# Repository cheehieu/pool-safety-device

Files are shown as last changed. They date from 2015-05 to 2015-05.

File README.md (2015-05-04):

pool-safety-device
==================

<iframe width="640" height="480" src="https://sketchfab.com/models/5c79c15477054004a583eb45c18d26ab/embed" frameborder="0" allowfullscreen mozallowfullscreen="true" webkitallowfullscreen="true" onmousewheel=""></iframe>

<p style="font-size: 13px; font-weight: normal; margin: 5px; color: #4A4A4A;">
    <a href="https://sketchfab.com/models/5c79c15477054004a583eb45c18d26ab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" target="_blank" style="font-weight: bold; color: #1CAAD9;">Pool Safety Device</a>
    by <a href="https://sketchfab.com/hieu?utm_source=oembed&utm_medium=embed&utm_campaign=5c79c15477054004a583eb45c18d26ab" target="_blank" style="font-weight: bold; color: #1CAAD9;">hieu</a>
    on <a href="https://sketchfab.com?utm_source=oembed&utm_medium=embed&utm_campaign=5c79c15477054004a583eb45c18d26ab" target="_blank" style="font-weight: bold; color: #1CAAD9;">Sketchfab</a>
</p>

## Overview

Collaborating with marketing and fine arts students, we designed a device to prevent children from drowning in home swimming pools. The device consisted of two parts: an external sensor (wristband worn by the user), and an internal control panel (base station mounted in the home).

This project was developed in the spring of 2011 for USC's Embedded System Design Laboratory (EE-459) course, taught by professor Allan Weber. It was a senior capstone design, which involved the specification, design, implementation, testing, and documentation of a digital system project using embedded processors, programmable logic, analog I/O interfaces and application specific hardware. My engineering teammates included Christopher Cortes, Bauryrzhan Krykpayev, Alexander Nobles, Steven Spinn, and Steph Shinohara.

## Hardware
The wristband alert system contains a water-detection circuit, which uses the conductivity of water to bridge the connection between two probes. Once water is detected&mdash;indicating unwanted pool access&mdash;a message is sent to the base station over an RF link, which then sounds an alarm to alert the homeowners. 

### Electrical Prototype
A functional prototype was built on wire-wrapped boards. The wristband prototype housed the op amp based water detection circuit, Freescale MC908JL15 microcontroller, wireless RF transceiver, monochromatic graphic LCD, 4MHz clock, voltage regulator, battery monitor, buzzer, and push-buttons/LEDs for user input/output. 



The base station prototype included a 24x2 character display, 4x4 keypad interface and encoder, Freescale MC908JL15 microcontroller, wireless RF transceiver, and a high-decibel buzzer.



A mockup PCB was designed to ensure the prototype could fit on a watchface-sized wristband. Not including the batteries, all of the electrical components can fit on the back of the LCD, which is 45mm x 45mm.  The thickness is about 4mm.



### Production Mockup
A production-ready mockup was created in collaboration with marketing and fine arts students. With their expertise, we developed a product that was both commercially viable and aesthetically pleasing.





## Software

### Wristband
The wristband is used to display and communicate status to a base station monitor. Once the presence of water is detected, the LEDs and buzzer alert the user of unwanted pool access. A GPIO interrupt is then generated on the microcontroller, commanding it to transmit the alert status to the monitor. 

The RFM22B 433MHz ISM band wireless transceiver uses a standard 4-wire SPI interface to communicate with the microcontroller. Because the JL16 does not have dedicated SPI pins, the serial protocol was implemented in software on GPIO lines (bit banging). This entailed writing low-level software functions to perform reading and writing of the transceiver’s registers, which involved controlling the clock, data, and device select pins.

The LCD features a battery life indicator, which displays the output of an 8-bit ADC used to monitor the system voltage input. The display also features a fish animation to entertain the child user. 

<iframe width="560" height="315" src="https://www.youtube.com/embed/oqmXTrBO6uU" frameborder="0" allowfullscreen></iframe>

### Base Station
The RF transceiver is used to provide a wireless communication interface for both the wristband and the base station monitor, allowing transmission of the alarm signal as well as a few other remote functions.

The "Sync" function establishes a connection between the wristband and base station. If the two devices are not synchronized, then any action that the wristband does will not be acted upon by the base station, and vice-versa. The Sync function is achieved through a series of handshaking between the wristband and the base station monitor. Both devices will display a message if the sync is successful.

The "Locate" function is designed to allow the user to find a misplaced wristband by emitting a continuous beep from the wristband. When the user selects the Locate function in the monitor's menu, all wristbands synced with the base station will begin to beep.

When the alarm is enabled, the wristband will send out an alarm packet on the transceiver if it detects water on its water detection circuit. When the base station receives the alarm, it checks its wristband list for a match on the ID bytes. If they match, a warning message is displayed the the buzzer alarm sounds. The user must then enter their password to disable the system, which will stop the alarm.



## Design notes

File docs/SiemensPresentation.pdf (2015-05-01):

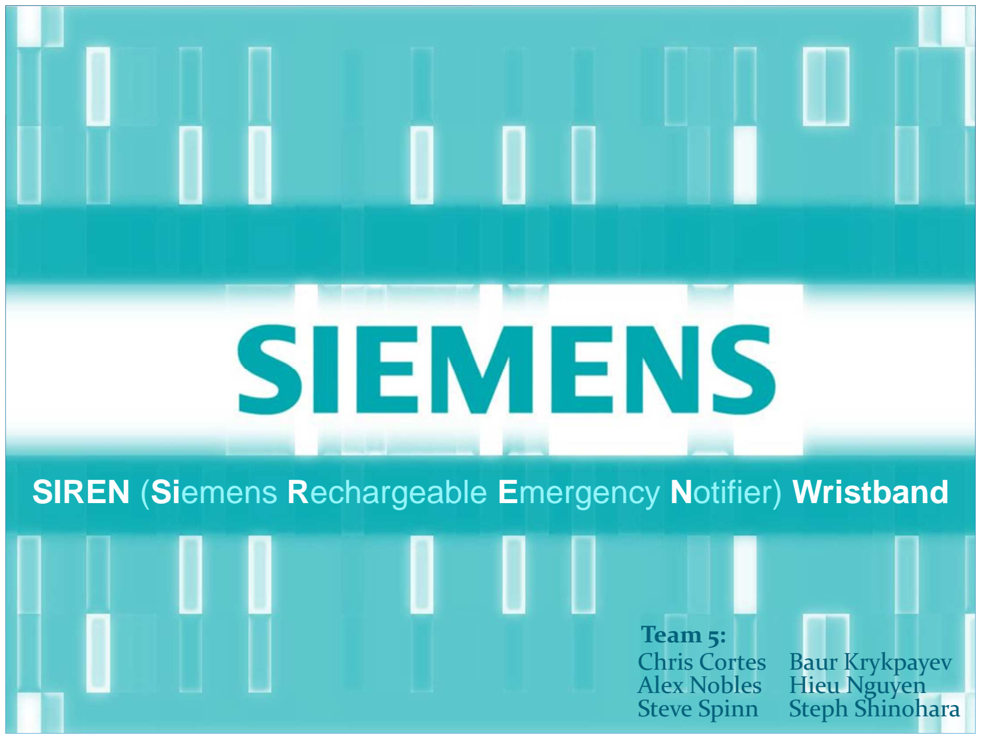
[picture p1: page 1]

Team 5:

SIREN (Siemens Rechargeable Emergency Notifier) Wristband

Chris Cortes
Alex Nobles
Steve Spinn

Baur Krykpayev
Hieu Nguyen Steph Shinohara

# Agenda

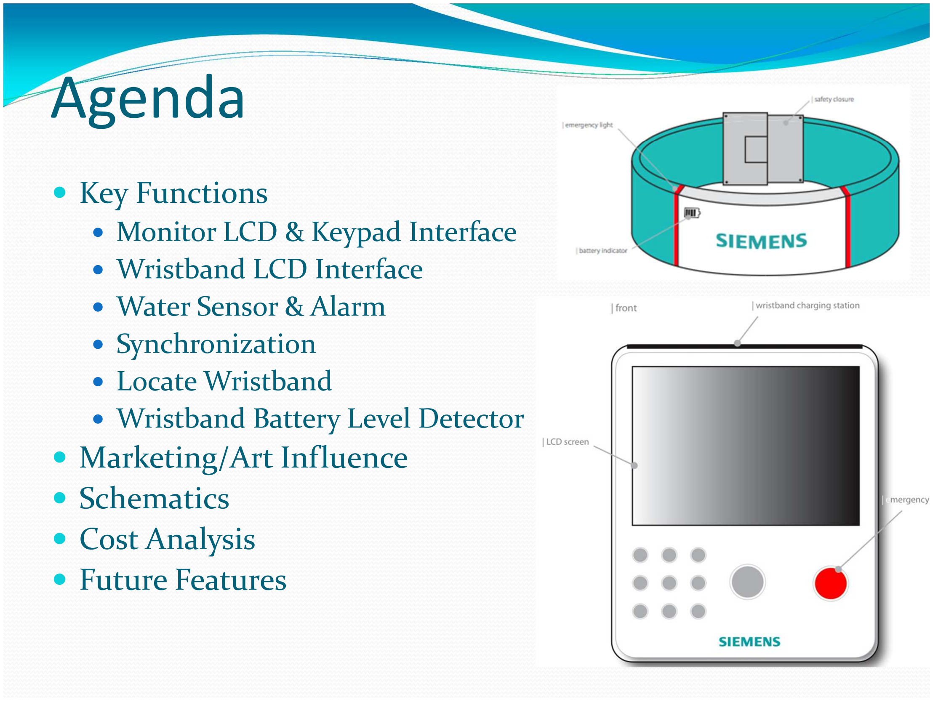
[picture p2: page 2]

Key Functions
Monitor LCD & Keypad Interface Wristband LCD Interface
Water Sensor & Alarm
Synchronization
Locate Wristband
Wristband Battery Level Detector Marketing/Art Influence
Schematics
Cost Analysis
Future Features

# Marketing/Art Influence

Based parts choices on Marketing plan
Chose cheaper, more reliable design

Art students had idea to include graphic LCD to entertain child

Added more functionality to this idea and displayed status on screen

## Monitor LCD & Keypad Interface

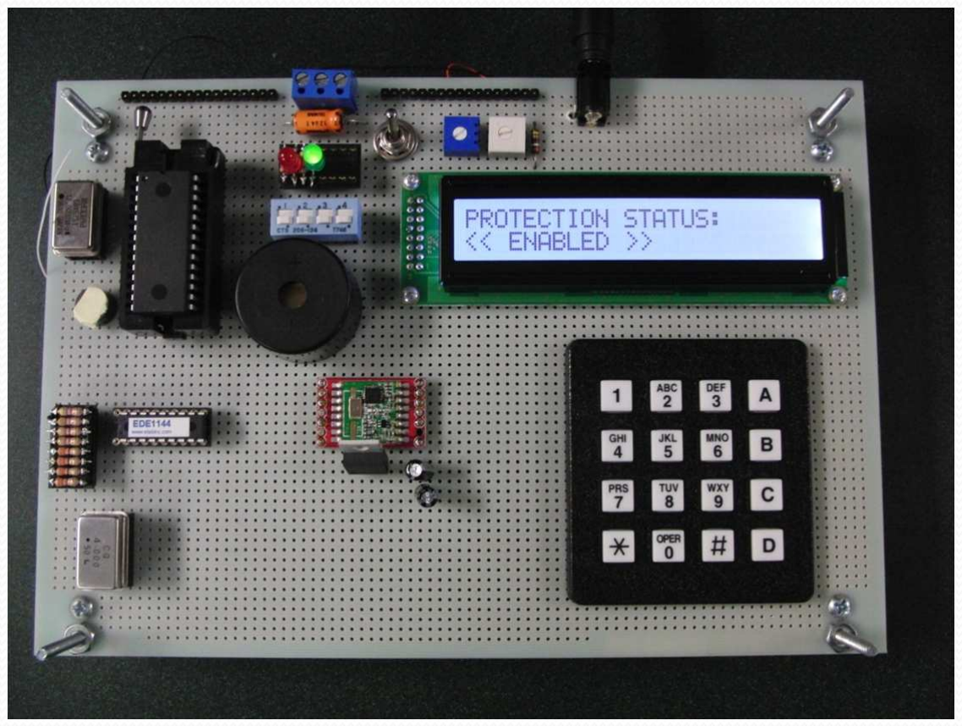
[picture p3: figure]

LCD: 24 x 2 character screen

User input: 4 x 4 keypad

Security: 4-digit password

Power Source: 5V Wall Adapter Configurable for
rechargeable battery

Audio: alert buzzer, keypad feedback

# Monitor Schematic

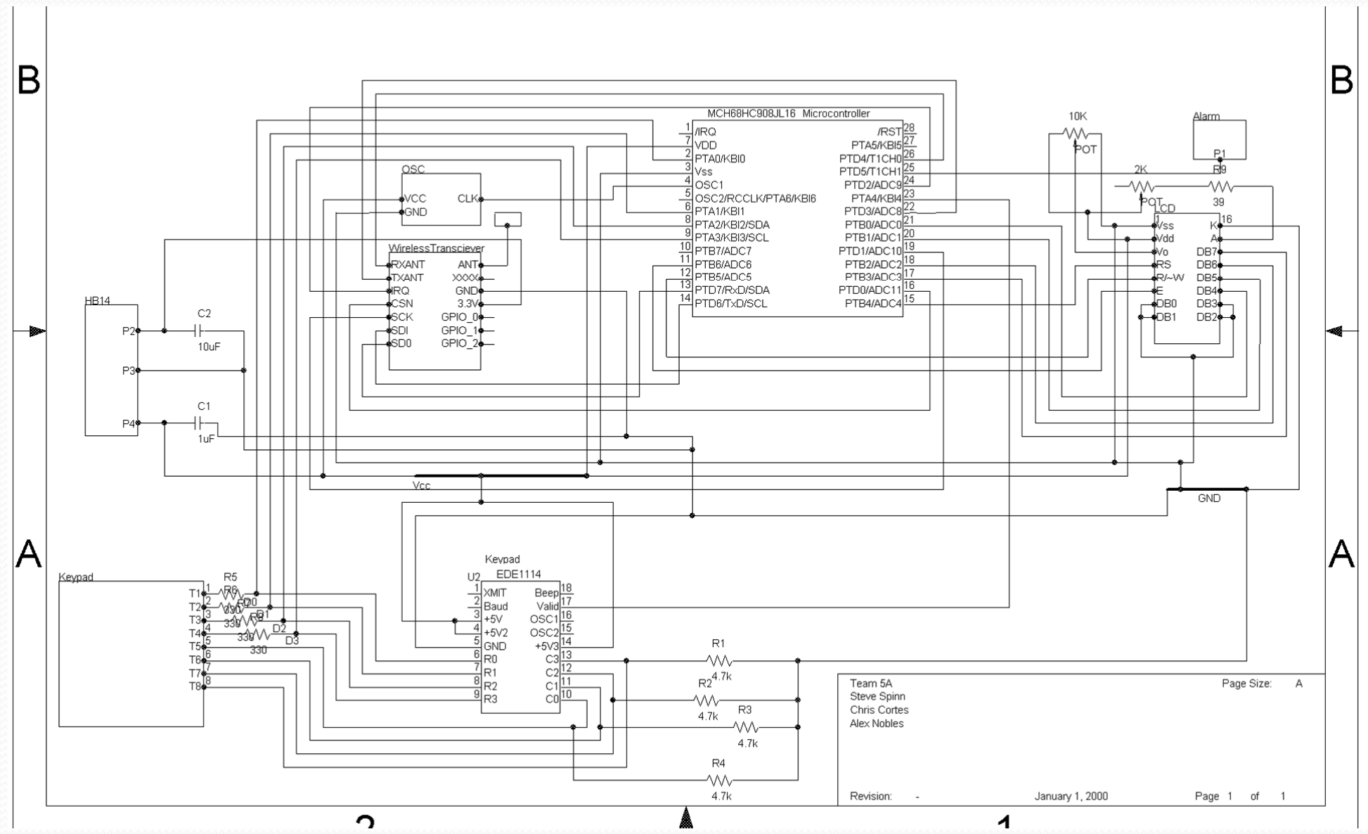
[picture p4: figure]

# Wristband Components

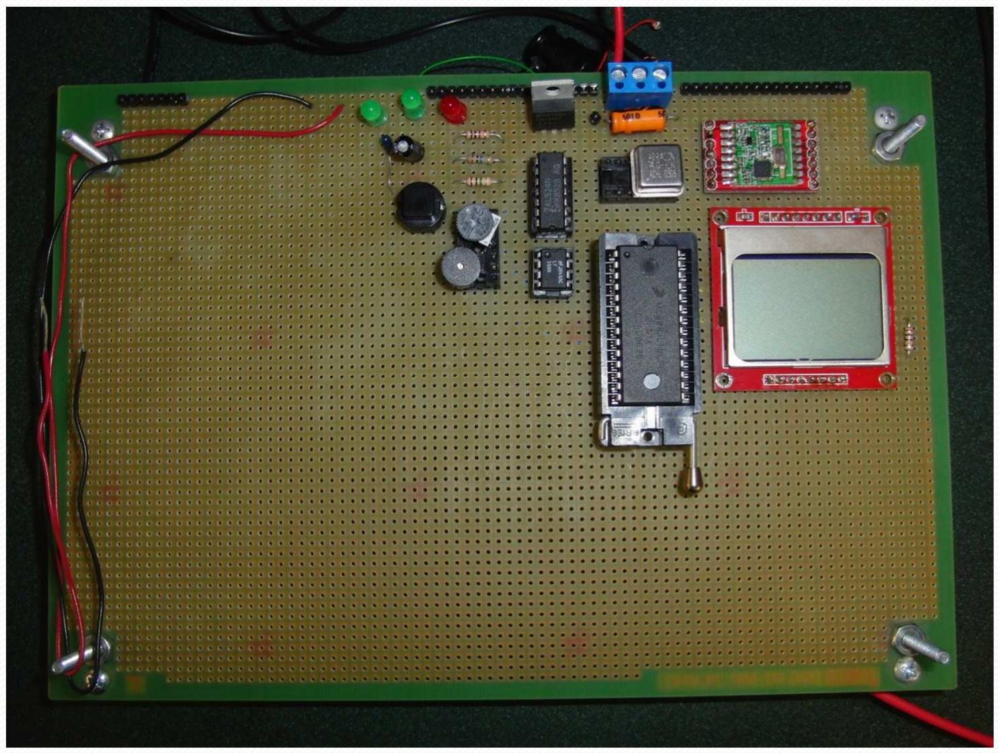
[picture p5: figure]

# Printed Circuit Board

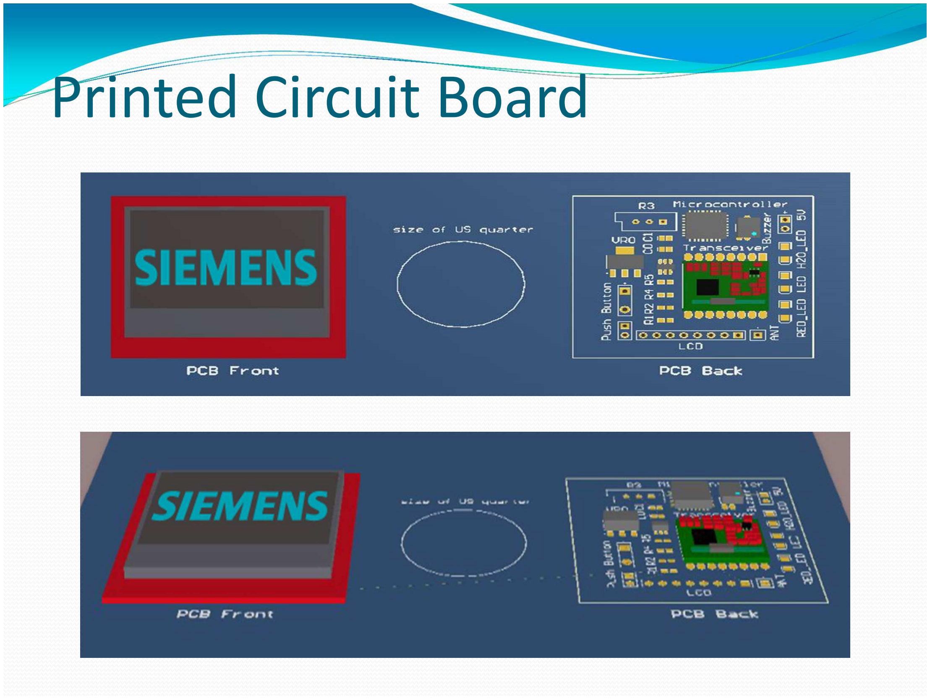
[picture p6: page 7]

# Wristband Schematic

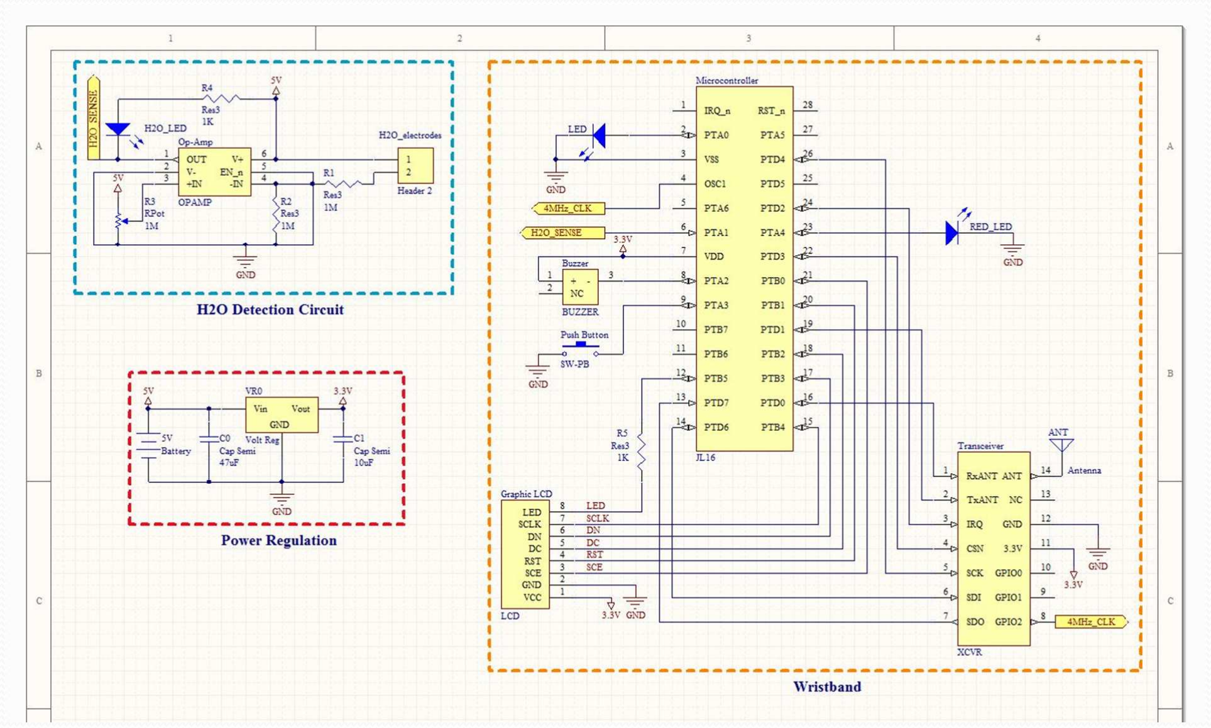
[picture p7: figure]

# Wristband LCD Interface

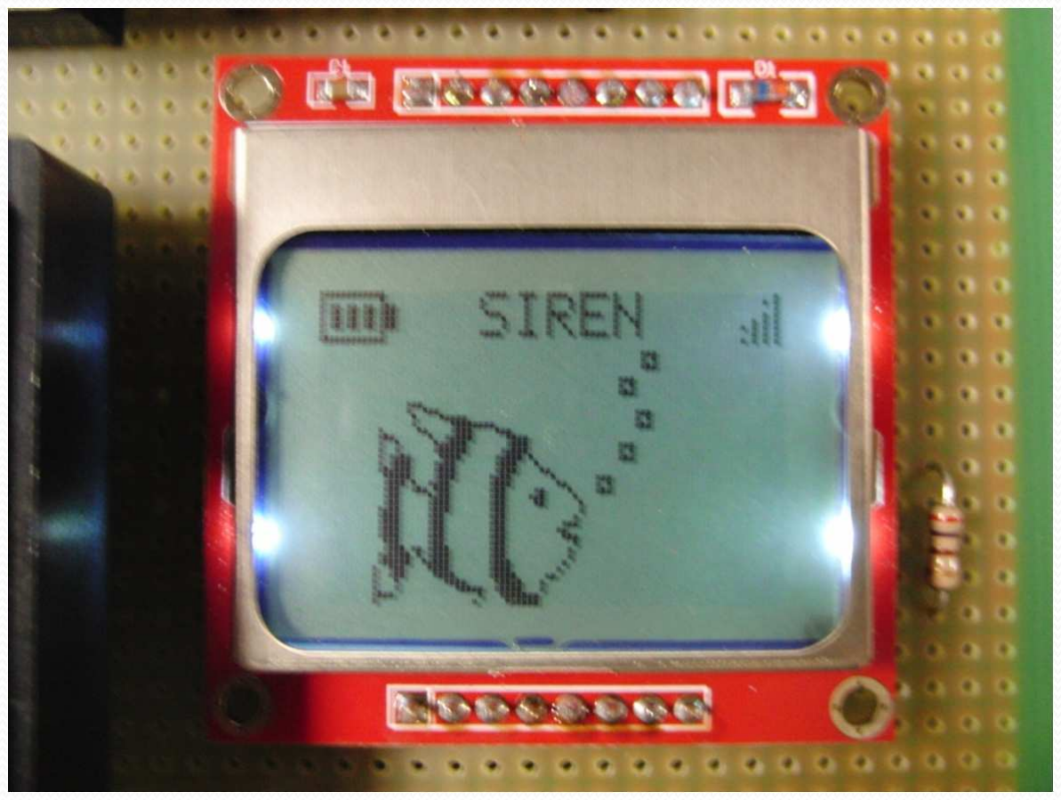
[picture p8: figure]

On startup/recharge:
Siemens logo displayed

Fish Animation for
certain period of time

If inactive, goes into
idle state (LCD off)

# Synchronization - Monitor

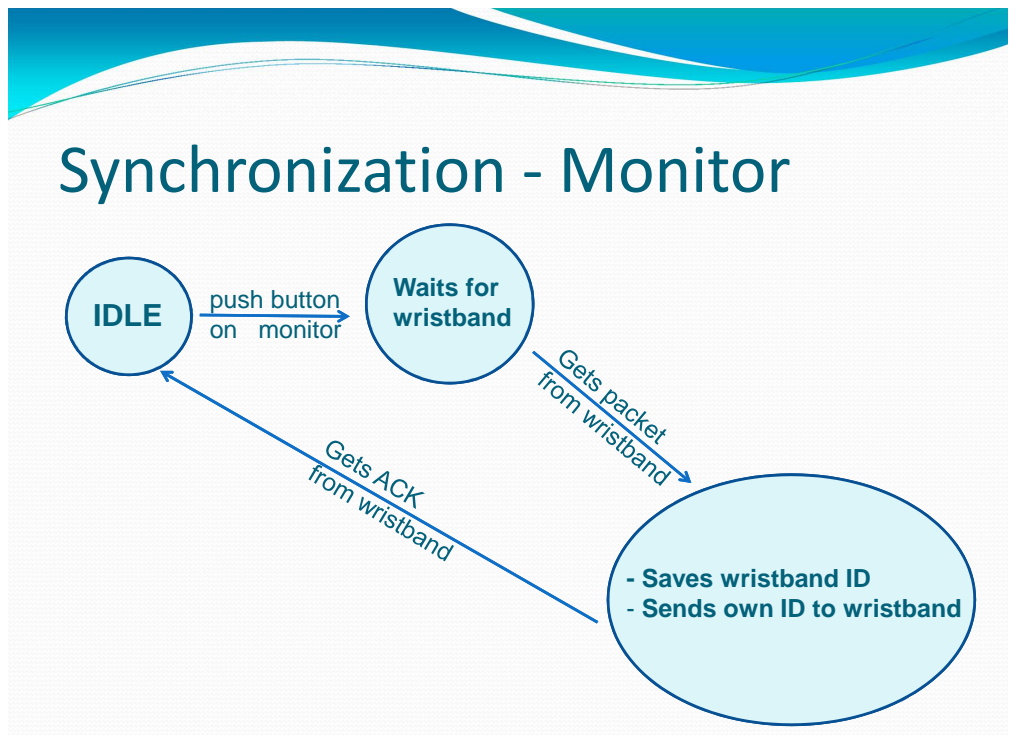
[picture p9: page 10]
push button on monitor; IDLE; Waits for wristband

- Saves wristband ID - Sends own ID to wristband

# Synchronization - Wristband

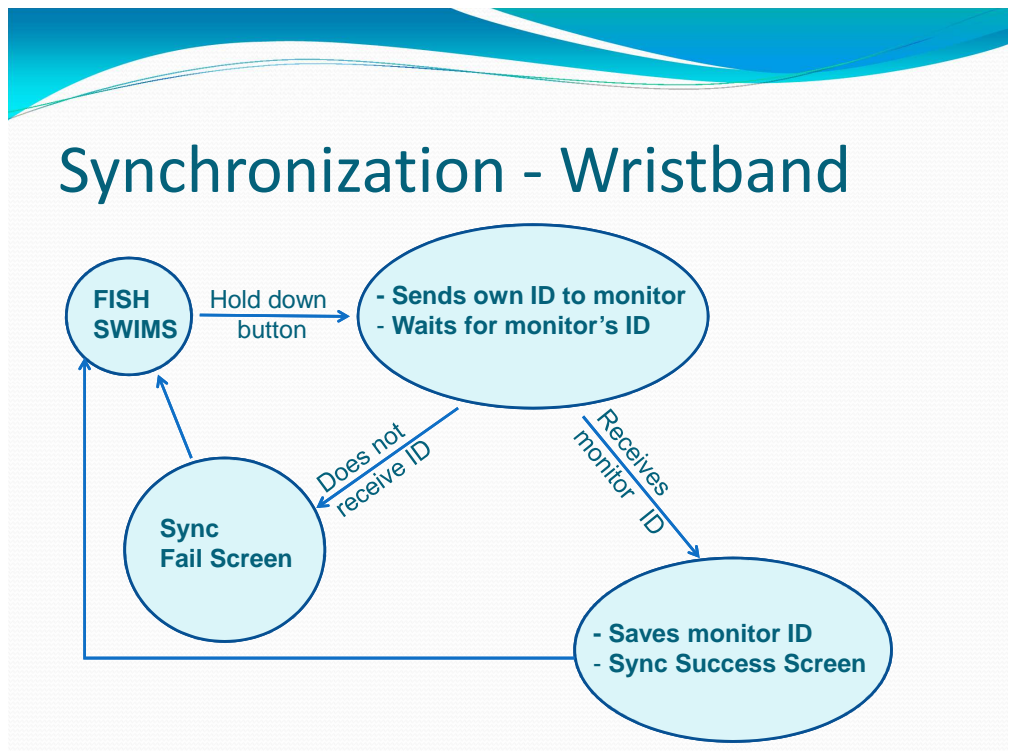
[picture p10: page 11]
FISH SWIMS; Sync Fail Screen; Hold down button

- Sends own ID to monitor
- Waits for monitor’s ID

- Saves monitor ID
- Sync Success Screen

# Locate Wristband

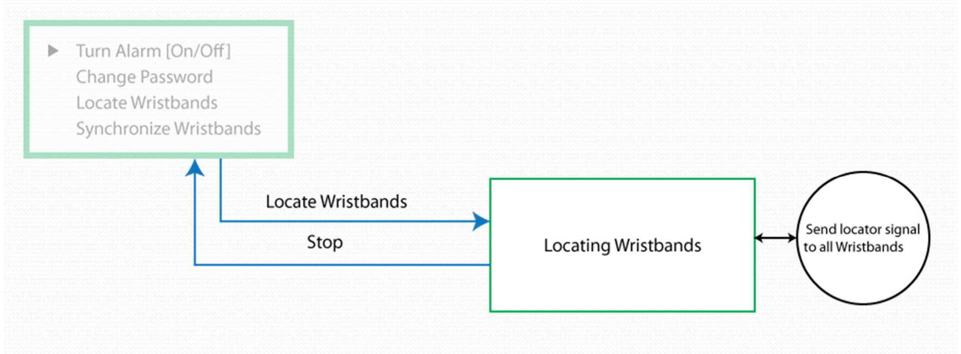
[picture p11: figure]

# Locate Wristband

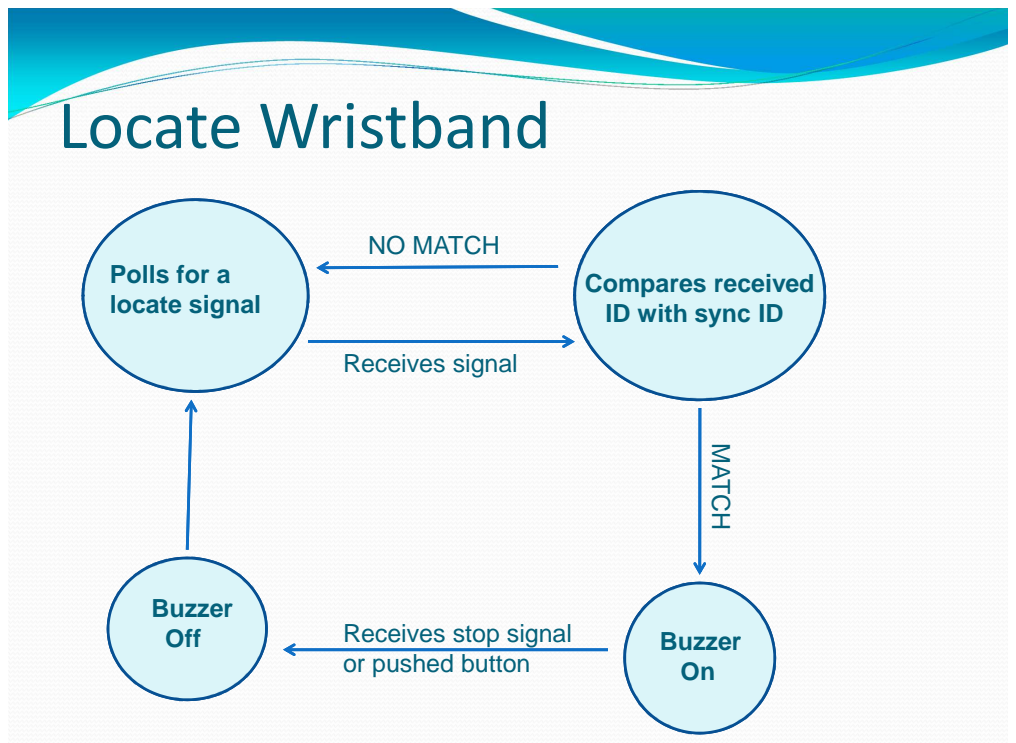
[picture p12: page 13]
MATCH; Polls for a; locate signal; Compares received ID with sync ID; Buzzer On; Buzzer Off; NO MATCH; Receives signal

Receives stop signal
or pushed button

# Set/Change Password

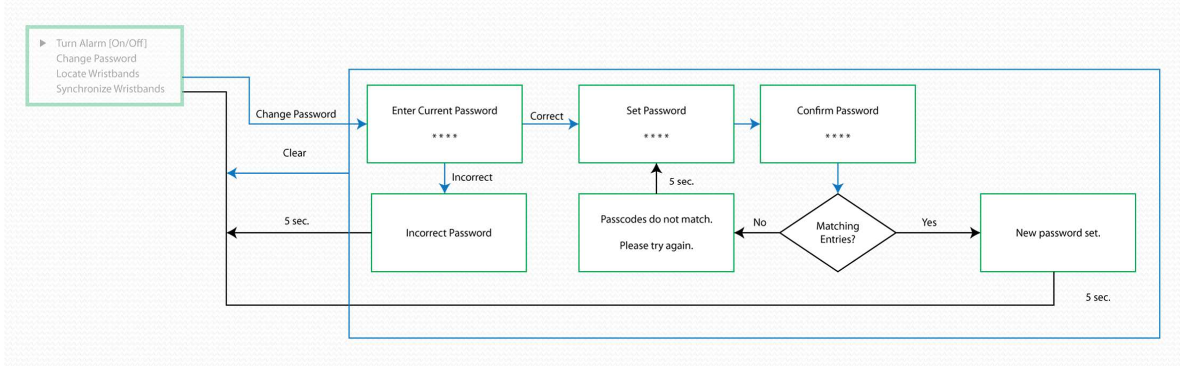
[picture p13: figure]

# Water Sensor & Alarm

Wristband:
Presence of water completes circuit
Triggers interrupt to transmit alert to monitor

If monitor is armed:
Waits to receive alert from wristband
Checks to see that synced wristband ID is sending alert Buzzer sounds until correct password is entered

## Wristband Battery Level Detector

Uses transceiver to monitor the current battery voltage Updates LCD to indicate battery level

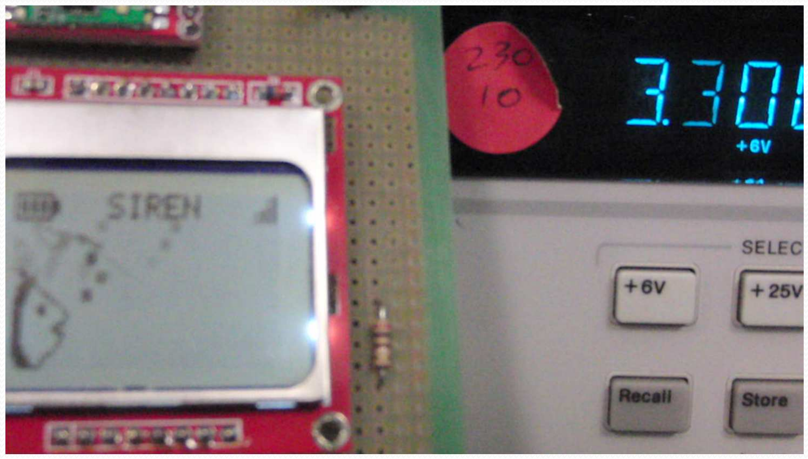
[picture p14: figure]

Part | Quantity | Bulk Unit Cost
Microcontroller | 1 | $ 1.74
Transceiver | 1 | $ 9.56
Buzzer | 1 | $ 3.49
24x2 LCD | 1 | $ 6.96
4x4 Keypad | 1 | $ 14.34
Miscellaneous (resistors, LEDs, voltage regulator, etc.) | | $ 1.00
TOTAL: | | $ 37.09

# Monitor Cost Analysis

# Wristband Cost Analysis

Part | Quantity | Bulk Unit Cost
Microcontroller | 1 | $ 1.74
Transceiver | 1 | $ 9.56
Buzzer | 1 | $ 0.25
Nokia Graphic LCD (84x48) | 1 | $ 7.96
Battery | 2 | $ 0.28
Miscellaneous (resistors, LEDs, voltage regulator, etc.) | | $ 1.00
TOTAL: | | $ 21.03

# Future Features

Rechargeable batteries

Interactive wristband functions

Display wireless signal strength

Verify functionality of transceiver underwater

## THANKS FOR YOUR ATTENTION!!

## DEMONSTRATION NOW!!!

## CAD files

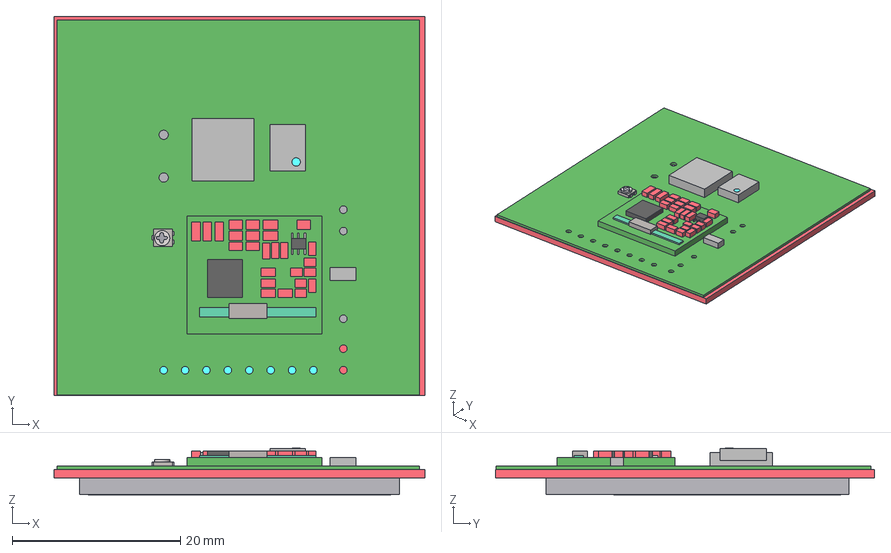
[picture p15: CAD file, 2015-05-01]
3d/wristband.step
44.0 x 45.0 x 5.53 mm
Board
Extruded x 52

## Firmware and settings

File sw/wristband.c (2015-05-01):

/*************************************************************
*       Siemens Re-chargeable Emergency Notifier Wristband (SIREN)
*       EE459 Spring 2011 Team 5B (wristband): Hieu Nguyen, Bauyrkhan Krykpayev, Stephanie Shinohara
*
*       Port A, bit 0 - output to green LED anode (1 = LED on, 0 = LED off)
*       Port A, bit 1 - input from water-immersion sensor (0 = H2O, 1 = no H2O)
*       Port A, bit 2 - output to buzzer (1 = off, 0 = on)
*       Port A, bit 3 - input from button (0 = pressed, 1 = not pressed)
*       Port A, bit 4 - output to red LED anode (1 = LED on, 0 = LED off)
*
*       Graphic LCD 84x48 pixels:
*       Port B, bit 0 - LCD chip enable  (active high)
*       Port B, bit 1 - LCD reset (active low)
*       Port B, bit 2 - LCD D/~C (1 = Data being transmitted, 0 = Control)
*       Port B, bit 3 - LCD serial data line
*       Port B, bit 4 - LCD clock for serial interface
*       Port B, bit 5 - LCD backlight power supply
*
*       Transceiver
*       Port D, bit 0 - RxAnt
*       Port D, bit 1 - TxAnt
*       Port D, bit 2 - IRQ
*       Port D, bit 3 - CSN
*       Port D, bit 4 - SCK
*       Port D, bit 6 - SDI
*       Port D, bit 7 - SDO
*
*************************************************************/

#include <hidef.h> /* for EnableInterrupts macro */
#include "derivative.h" /* include peripheral declarations */

typedef unsigned char uchar;
typedef unsigned int uint;


#define LED_GREEN      PTA_PTA0
#define H2O_SENSE      PTA_PTA1
#define BUZZER         PTA_PTA2
#define BUTTON         !PTA_PTA3
#define LED_RED        PTA_PTA4

#define LCD_SCE        PTB_PTB0
#define LCD_RST        PTB_PTB1
#define LCD_DC         PTB_PTB2
#define LCD_DN         PTB_PTB3
#define LCD_SCLK       PTB_PTB4
#define LCD_BACKLIGHT  PTB_PTB5

#define XCVR_RxANT    PTD_PTD0   
#define XCVR_TxANT    PTD_PTD1    
#define XCVR_IRQ      PTD_PTD2   
#define XCVR_CSN      PTD_PTD3 
#define XCVR_SCK      PTD_PTD4   
#define XCVR_SDI      PTD_PTD6 
#define XCVR_SDO      PTD_PTD7

#define LCD_CTR  0
#define LCD_DAT  1

#define LCD_WIDTH  84
#define LCD_HEIGHT 48

#define BATTERY_HIGH     3
#define BATTERY_MED      2
#define BATTERY_LOW      1
#define BATTERY_EMPTY    0



void interrupt waterISR(void);  
void system_init(void);  
void wait500ms(void); 
void wait100ms(void);  
void wait5ms(void);
void low_battery_detect(void);
void wristband_sync(void);
void locate_wristband(void);

void lcd_init(void); 
void lcd_display(unsigned char array_b[], char f); 
void lcd_bmp(unsigned char array_b[], unsigned char array_w[], unsigned char array_f[]);
void lcd_full_bmp(unsigned char array[]);
void lcd_sync(unsigned char array_b[]);
void lcd_clear(void); 
void lcd_backlight(char enabled);
void lcd_write(char dc, char data); 
 
void send_read_address(uchar addr);   
uchar send_command(void);  
void to_rx_mode(void);  
void to_tx_mode(unsigned char buf[], int size);
void rx_reset(void);  
void init_RFM22(void);
char readByte(char address);
void writeByte(char address, char data);
void write1();
void write0();


//Global Variables
uchar water_buf[17] = {0x30, 0xab, 0xcd, 0xef, 0x34, 0x35, 0x36, 0x37, 0x38, 0x39, 0x3A, 0x3B, 0x3C, 0x3D, 0x3E, 0x3F, 0x78};
uchar locate_buf[17] = {0x29, 0x31, 0x32, 0x33, 0x34, 0x35, 0x36, 0x37, 0x38, 0x39, 0x3A, 0x3B, 0x3C, 0x3D, 0x3E, 0x3F, 0x78};
uchar locate_buf2[17] = {0x28, 0x31, 0x32, 0x33, 0x34, 0x35, 0x36, 0x37, 0x38, 0x39, 0x3A, 0x3B, 0x3C, 0x3D, 0x3E, 0x3F, 0x78};
uchar sync_send_buf[17] = {0x27, 0xab, 0xcd, 0xef, 0x34, 0x35, 0x36, 0x37, 0x38, 0x39, 0x3A, 0x3B, 0x3C, 0x3D, 0x3E, 0x3F, 0x78};
uchar sync_rec_buf[17] = {0x26, 0x12, 0x34, 0x56, 0x34, 0x35, 0x36, 0x37, 0x38, 0x39, 0x3A, 0x3B, 0x3C, 0x3D, 0x3E, 0x3F, 0x78};
uchar sync_confirm_buf[17] = {0x25, 0xab, 0xcd, 0xef, 0x34, 0x35, 0x36, 0x37, 0x38, 0x39, 0x3A, 0x3B, 0x3C, 0x3D, 0x3E, 0x3F, 0x78};
uchar RF_RXBUF[35];
uchar * batt_level;
uchar base_id[3] = {0x00, 0x00, 0x00};
int battery_level;
uchar one = 1;


#pragma CODE_SEG MY_ISR_ROM

#pragma TRAP_PROC
void dummyISR(void)
{
}

#pragma CODE_SEG DEFAULT


const unsigned char siem [] = {
0x00, 0x00, 0x00, 0x00, 0x00, 0x00, 0x00, 0x00, 0x00, 0x00, 0x00, 0x00, 0x00, 0x00, 0x00, 0x00,
0x00, 0x00, 0x00, 0x00, 0x00, 0x00, 0x00, 0x00, 0x00, 0x00, 0x00, 0x00, 0x00, 0x00, 0x00, 0x00,
0x00, 0x00, 0x00, 0x00, 0x00, 0x00, 0x00, 0x00, 0x00, 0x00, 0x00, 0x00, 0x00, 0x00, 0x00, 0x00,
0x00, 0x00, 0x00, 0x00, 0x00, 0x00, 0x00, 0x00, 0x00, 0x00, 0x00, 0x00, 0x00, 0x00, 0x00, 0x00,
0x00, 0x00, 0x00, 0x00, 0x00, 0x00, 0x00, 0x00, 0x00, 0x00, 0x00, 0x00, 0x00, 0x00, 0x00, 0x00,
0x00, 0x00, 0x00, 0x00, 0x00, 0x80, 0xF0, 0xF0, 0xF0, 0x70, 0x70, 0x70, 0x70, 0x70, 0x00, 0x00,
0xF0, 0xF0, 0xF0, 0xF0, 0xF0, 0x00, 0x00, 0xF0, 0xF0, 0xF0, 0xF0, 0x70, 0x70, 0x70, 0x70, 0x70,
0x00, 0xF0, 0xF0, 0xF0, 0xF0, 0xF0, 0xF0, 0x80, 0x00, 0x00, 0x00, 0x80, 0xF0, 0xF0, 0xF0, 0xF0,
0xF0, 0x00, 0x00, 0x00, 0xF0, 0xF0, 0xF0, 0xF0, 0x70, 0x70, 0x70, 0x70, 0x70, 0x00, 0x00, 0x00,
0xF0, 0xF0, 0xF0, 0xF0, 0x80, 0x00, 0x00, 0xF0, 0xF0, 0xF0, 0xF0, 0x00, 0x80, 0xF0, 0xF0, 0xF0,
0x70, 0x70, 0x70, 0x70, 0x70, 0x00, 0x00, 0x00, 0x00, 0x0F, 0x7F, 0x7F, 0x7F, 0x7F, 0xFC, 0xF0,
0xE0, 0xE0, 0xE0, 0x00, 0xFF, 0xFF, 0xFF, 0xFF, 0xFF, 0x00, 0x00, 0xFF, 0xFF, 0xFF, 0xFF, 0x70,
0x70, 0x70, 0x70, 0x00, 0x00, 0xFF, 0xFF, 0xFF, 0xFF, 0x0F, 0xFF, 0xFF, 0xE0, 0xE0, 0xE0, 0xFF,
0x0F, 0xFF, 0xFF, 0xFF, 0xFF, 0x00, 0x00, 0x00, 0xFF, 0xFF, 0xFF, 0xFF, 0x70, 0x70, 0x70, 0x70,
0x00, 0x00, 0x00, 0x00, 0xFF, 0xFF, 0x7F, 0x7F, 0xFF, 0xF0, 0x80, 0xFF, 0xFF, 0xFF, 0xFF, 0x00,
0x0F, 0x7F, 0x7F, 0x7F, 0x7F, 0xFC, 0xF0, 0xF0, 0xF0, 0x80, 0x00, 0x00, 0x00, 0x30, 0x30, 0x30,
0x30, 0x30, 0x30, 0x3F, 0x1F, 0x1F, 0x1F, 0x00, 0x3F, 0x3F, 0x3F, 0x3F, 0x3F, 0x00, 0x00, 0x3F,
0x3F, 0x3F, 0x3F, 0x30, 0x30, 0x30, 0x30, 0x30, 0x00, 0x3F, 0x3F, 0x3F, 0x3F, 0x00, 0x00, 0x1F,
0x3F, 0x3F, 0x3F, 0x00, 0x00, 0x3F, 0x3F, 0x3F, 0x3F, 0x00, 0x00, 0x00, 0x3F, 0x3F, 0x3F, 0x3F,
0x30, 0x30, 0x30, 0x30, 0x30, 0x00, 0x00, 0x00, 0x3F, 0x3F, 0x00, 0x00, 0x03, 0x3F, 0x3F, 0x3F,
0x3F, 0x3F, 0x3F, 0x00, 0x30, 0x30, 0x30, 0x30, 0x30, 0x30, 0x33, 0x3F, 0x3F, 0x0F, 0x00, 0x00,
0x00, 0x00, 0x00, 0x00, 0x00, 0x00, 0x00, 0x00, 0x00, 0x00, 0x00, 0x00, 0x00, 0x00, 0x00, 0x00,
0x00, 0x00, 0x00, 0x00, 0x00, 0x00, 0x00, 0x00, 0x00, 0x00, 0x00, 0x00, 0x00, 0x00, 0x00, 0x00,
0x00, 0x00, 0x00, 0x00, 0x00, 0x00, 0x00, 0x00, 0x00, 0x00, 0x00, 0x00, 0x00, 0x00, 0x00, 0x00,
0x00, 0x00, 0x00, 0x00, 0x00, 0x00, 0x00, 0x00, 0x00, 0x00, 0x00, 0x00, 0x00, 0x00, 0x00, 0x00,
0x00, 0x00, 0x00, 0x00, 0x00, 0x00, 0x00, 0x00, 0x00, 0x00, 0x00, 0x00, 0x00, 0x00, 0x00, 0x00,
0x00, 0x00, 0x00, 0x00, 0x00, 0x00, 0x00, 0x00, 0x00, 0x00, 0x00, 0x00, 0x00, 0x00, 0x00, 0x00,
0x00, 0x00, 0x00, 0x00, 0x00, 0x00, 0x00, 0x00, 0x00, 0x00, 0x00, 0x00, 0x00, 0x00, 0x00, 0x00,
0x00, 0x00, 0x00, 0x00, 0x00, 0x00, 0x00, 0x00, 0x00, 0x00, 0x00, 0x00, 0x00, 0x00, 0x00, 0x00,
0x00, 0x00, 0x00, 0x00, 0x00, 0x00, 0x00, 0x00, 0x00, 0x00, 0x00, 0x00, 0x00, 0x00, 0x00, 0x00,
0x00, 0x00, 0x00, 0x00, 0x00, 0x00, 0x00, 0x00, 0x00, 0x00, 0x00, 0x00, 0x00, 0x00, 0x00, 0x00,
0x00, 0x00, 0x00, 0x00, 0x00, 0x00, 0x00, 0x00, 
};

const unsigned char siren [] ={  
0x00, 0x00, 0x00, 0x00, 0x00, 0x00, 0x00, 0x00, 0x00, 0x00, 
0x00, 0x00, 0x00, 0x00, 0x00, 0x46, 0x49, 0x49, 0x49, 0x31, 
0x00, 0x00, 0x41, 0x7f, 0x41, 0x00, 0x00, 0x7f, 0x09, 0x19,
0x29, 0x46, 0x00, 0x7f, 0x49, 0x49, 0x49, 0x41, 0x00, 0x7f,
0x04, 0x08, 0x10, 0x7f, 0x00, 0x00, 0x00, 0x00, 0x00, 0x00,
0x00, 0x00, 0x00, 0x00, 0x00, 0x00, 0x00, 0x00, 0x00, 0x00,
0x00, 0x00, 0xA0, 0x00, 0xF0, 0x00, 0xFA, 0x00, 0xFF, 0x00, 
};

const unsigned char sync [] = {
0x00, 0x00, 0x00, 0x00, 0xC0, 0xE0, 0x20, 0x20, 0x20, 0xE0, 0xC0, 0x00, 0x00, 0x00, 0x00, 0x00,
0x00, 0x00, 0x00, 0x00, 0x00, 0x00, 0x00, 0x00, 0x00, 0x00, 0x00, 0x00, 0x00, 0x00, 0x00, 0x00,
0x00, 0x00, 0x00, 0x00, 0x60, 0x60, 0x00, 0x00, 0x00, 0x00, 0x00, 0x00, 0x00, 0x00, 0x00, 0x00,
0x00, 0x00, 0x00, 0x00, 0x00, 0x00, 0x00, 0x00, 0x00, 0x00, 0x00, 0x00, 0x00, 0x00, 0x00, 0x00,
0x00, 0x00, 0x00, 0x00, 0x00, 0x00, 0x00, 0x00, 0x00, 0x00, 0x00, 0x00, 0x00, 0x00, 0x00, 0x00,
0x00, 0x00, 0x00, 0x00, 0x00, 0x00, 0x00, 0x00, 0x31, 0x73, 0x42, 0x46, 0x44, 0x7C, 0x38, 0x00,
0x03, 0x0F, 0x3C, 0xF0, 0xF0, 0x3C, 0x0F, 0x03, 0x00, 0x7F, 0x7F, 0x01, 0x01, 0x7F, 0x7E, 0x00,
0x00, 0x3E, 0x7F, 0x41, 0x41, 0x63, 0x22, 0x00, 0x7F, 0x7F, 0x00, 0x00, 0x7F, 0x7F, 0x01, 0x01,
0x7F, 0x7E, 0x00, 0x00, 0x3E, 0x7F, 0x41, 0x41, 0xFF, 0xFF, 0x00, 0x00, 0x00, 0x00, 0x00, 0x00,
0x60, 0x60, 0x00, 0x00, 0x00, 0x00, 0x00, 0x00, 0x60, 0x60, 0x00, 0x00, 0x00, 0x00, 0x00, 0x00,
0x60, 0x60, 0x00, 0x00, 0x00, 0x00, 0x00, 0x00, 0x00, 0x00, 0x00, 0x00, 0x00, 0x00, 0x00, 0x00,
0x00, 0x00, 0x00, 0x00, 0x00, 0x02, 0x03, 0x01, 0x00, 0x00, 0x00, 0x00, 0x00, 0x00, 0x00, 0x00,
0x00, 0x00, 0x00, 0x00, 0x00, 0x00, 0x00, 0x00, 0x00, 0x00, 0x00, 0x00, 0x00, 0x00, 0x00, 0x00,
0x00, 0x00, 0x00, 0x00, 0x00, 0x00, 0x00, 0x00, 0x01, 0x03, 0x02, 0x02, 0x03, 0x01, 0x00, 0x00,
0x00, 0x00, 0x00, 0x00, 0x00, 0x00, 0x00, 0x00, 0x00, 0x00, 0x00, 0x00, 0x00, 0x00, 0x00, 0x00,
0x00, 0x00, 0x00, 0x00, 0x00, 0x00, 0x00, 0x00, 0x00, 0x00, 0x00, 0x00, 
};

const unsigned char batt_empty [] = {
0xFF, 0x81, 0x81, 0x81, 0x81, 0x81, 0x81, 0x81, 0x81, 0x81, 0x81, 0xFF, 0x3C, 0x3C, 
};

const unsigned char batt_low [] = {
0xFF, 0x81, 0xBD, 0xBD, 0x81, 0x81, 0x81, 0x81, 0x81, 0x81, 0x81, 0xFF, 0x3C, 0x3C, 
};

const unsigned char batt_med [] = {
0xFF, 0x81, 0xBD, 0xBD, 0x81, 0xBD, 0xBD, 0x81, 0x81, 0x81, 0x81, 0xFF, 0x3C, 0x3C, 
};

const unsigned char batt_high [] = {
0xFF, 0x81, 0xBD, 0xBD, 0x81, 0xBD, 0xBD, 0x81, 0xBD, 0xBD, 0x81, 0xFF, 0x3C, 0x3C, 
};

const unsigned char fish0 [] = {
0x00, 0x00, 0x00, 0x00, 0x00, 0x00, 0x00, 0x00, 0x00, 0x00, 0x00, 0x00, 0x00, 0x00, 0x00, 0x00,
0x00, 0x00, 0x00, 0x00, 0x70, 0x50, 0x70, 0x00, 0x00, 0x00, 0x07, 0x05, 0x07, 0x00, 0x00, 0x00,
0x00, 0x00, 0x00, 0x00, 0x00, 0x00, 0x00, 0x00, 0x00, 0x00, 0x00, 0x00, 0x00, 0x00, 0x00, 0x00,
0x00, 0x00, 0x00, 0x00, 0x00, 0x00, 0x00, 0x00, 0x00, 0x00, 0x00, 0x00, 0x00, 0x00, 0x00, 0x00,
0x00, 0x00, 0x00, 0x00, 0x00, 0x00, 0x00, 0x00, 0x00, 0x00, 0x00, 0x00, 0x00, 0x00, 0x00, 0x00,
0x00, 0x00, 0x00, 0x00, 0x20, 0x20, 0x40, 0x40, 0xC0, 0x80, 0x80, 0x80, 0x00, 0x00, 0x00, 0x00,
0x00, 0x00, 0x00, 0x00, 0x00, 0x00, 0x00, 0x00, 0x00, 0x00, 0x00, 0x0E, 0x0A, 0x0E, 0xC0, 0x40,
0xC0, 0x00, 0x00, 0x00, 0x00, 0x00, 0x00, 0x00, 0x00, 0x00, 0x00, 0x00, 0x00, 0x00, 0x00, 0x00,
0x00, 0x00, 0x00, 0x00, 0x00, 0x00, 0x00, 0x00, 0x00, 0x00, 0x00, 0x00, 0x00, 0x00, 0x00, 0x00,
0x00, 0x00, 0x00, 0x00, 0x00, 0x00, 0x00, 0x00, 0x00, 0x00, 0x00, 0x00, 0x00, 0x00, 0x00, 0x00,
0x00, 0x00, 0x00, 0x00, 0x00, 0x00, 0x00, 0x00, 0x00, 0xE0, 0xFC, 0xFE, 0x7F, 0x1F, 0x07, 0x03,
0x04, 0x88, 0x90, 0x10, 0x20, 0x40, 0x40, 0x80, 0x00, 0x00, 0x00, 0x00, 0x00, 0x00, 0x38, 0x28,
0x38, 0x00, 0x01, 0x01, 0x01, 0x00, 0x00, 0x00, 0x00, 0x00, 0x00, 0x00, 0x00, 0x00, 0x00, 0x00,
0x00, 0x00, 0x00, 0x00, 0x00, 0x00, 0x00, 0x00, 0x00, 0x00, 0x00, 0x00, 0x00, 0x00, 0x00, 0x00,
0x00, 0x00, 0x00, 0x00, 0x00, 0x00, 0x00, 0x00, 0x00, 0x00, 0x00, 0x00, 0x00, 0x00, 0x00, 0x00,
0x00, 0x00, 0x00, 0x00, 0x00, 0x00, 0x00, 0x00, 0x00, 0x00, 0x00, 0x00, 0x00, 0xFF, 0xFF, 0xFF,
0x00, 0x00, 0x00, 0x00, 0x01, 0x03, 0x03, 0x00, 0x00, 0x20, 0x70, 0x50, 0xD9, 0x06, 0x00, 0x00,
0x00, 0x00, 0x00, 0x00, 0x00, 0x00, 0x00, 0x00, 0x00, 0x00, 0x00, 0x00, 0x00, 0x00, 0x00, 0x00,
0x00, 0x00, 0x00, 0x00, 0x00, 0x00, 0x00, 0x00, 0x00, 0x00, 0x00, 0x00, 0x00, 0x00, 0x00, 0x00,
0x00, 0x00, 0x00, 0x00, 0x00, 0x00, 0x00, 0x00, 0x00, 0x00, 0x00, 0x00, 0x00, 0x00, 0x00, 0x00,
0x00, 0x00, 0x00, 0x00, 0x00, 0x00, 0x00, 0x00, 0x00, 0x00, 0x00, 0x00, 0x00, 0x00, 0x00, 0x00,
0x00, 0x1F, 0x7F, 0xFF, 0xFC, 0xF0, 0xE0, 0x80, 0x80, 0x80, 0x60, 0x10, 0x10, 0x08, 0x04, 0x03,
0x00, 0x00, 0x00, 0x00, 0x00, 0x00, 0x00, 0x00, 0x00, 0x00, 0x00, 0x00, 0x00, 0x00, 0x00, 0x00,
0x00, 0x00, 0x00, 0x00, 0x00, 0x00, 0x00, 0x00, 0x00, 0x00, 0x00, 0x00, 0x00, 0x00, 0x00, 0x00,
0x00, 0x00, 0x00, 0x00, 0x00, 0x00, 0x00, 0x00, 0x00, 0x00, 0x00, 0x00, 0x00, 0x00, 0x00, 0x00,
0x00, 0x00, 0x00, 0x00, 0x00, 0x00, 0x00, 0x00, 0x00, 0x00, 0x00, 0x00, 0x00, 0x00, 0x00, 0x00,
0x00, 0x00, 0x00, 0x00, 
};

const unsigned char fish1 [] = {
0x00, 0xE0, 0x40, 0x40, 0x80, 0x00, 0x06, 0x1A, 0x22, 0x24, 0x44, 0x84, 0x88, 0xC8, 0xF8, 0xF8,
0xF8, 0x70, 0x10, 0x10, 0x10, 0x10, 0x20, 0x20, 0xE0, 0xC0, 0xC0, 0xC0, 0x00, 0x00, 0x00, 0x00,
0x00, 0x00, 0x00, 0x00, 0x00, 0x00, 0x00, 0x00, 0x00, 0x00, 0x00, 0x00, 0x00, 0x00, 0xE0, 0xA0,
0xE0, 0x07, 0x05, 0x07, 0x00, 0x00, 0x00, 0x00, 0x00, 0x00, 0x00, 0x00, 0x00, 0x00, 0x00, 0x00,
0x00, 0x00, 0x00, 0x00, 0x00, 0x00, 0x00, 0x00, 0x00, 0x00, 0x00, 0x00, 0x00, 0x00, 0x00, 0x00,
0x00, 0x00, 0x00, 0x00, 0x00, 0x0F, 0xF8, 0xFE, 0xFF, 0x3E, 0x1E, 0x60, 0x40, 0x40, 0xA0, 0xFD,
0xFF, 0xFF, 0x1F, 0x03, 0x01, 0x00, 0x00, 0x00, 0x00, 0xF0, 0xFE, 0xFF, 0x3F, 0x0F, 0x03, 0x01,
0x82, 0xC4, 0xC8, 0x08, 0x10, 0x20, 0x20, 0x40, 0x80, 0x00, 0x00, 0x00, 0x00, 0x00, 0x1C, 0x14,
0x1C, 0x00, 0x00, 0x00, 0x00, 0x00, 0x00, 0x00, 0x00, 0x00, 0x00, 0x00, 0x00, 0x00, 0x00, 0x00,
0x00, 0x00, 0x00, 0x00, 0x00, 0x00, 0x00, 0x00, 0x00, 0x00, 0x00, 0x00, 0x00, 0x00, 0x00, 0x00,
0x00, 0x00, 0x00, 0x00, 0x00, 0x00, 0x00, 0x00, 0x00, 0x3E, 0xFF, 0xFF, 0xFF, 0x80, 0x00, 0x80,
0x80, 0x00, 0xFF, 0xFF, 0xFF, 0x83, 0x00, 0x00, 0x00, 0x00, 0x00, 0x00, 0x00, 0xFF, 0xFF, 0xFF,
0x00, 0x00, 0x00, 0x00, 0x00, 0x01, 0x01, 0x00, 0x00, 0x10, 0x38, 0xA8, 0x6C, 0x03, 0x00, 0x00,
0x00, 0x00, 0x00, 0x00, 0x00, 0x00, 0x00, 0x00, 0x00, 0x00, 0x00, 0x00, 0x00, 0x00, 0x00, 0x00,
0x00, 0x00, 0x00, 0x00, 0x00, 0x00, 0x00, 0x00, 0x00, 0x00, 0x00, 0x00, 0x00, 0x00, 0x00, 0x00,
0x00, 0x00, 0x00, 0x00, 0x00, 0x00, 0x00, 0x00, 0x00, 0x00, 0x00, 0x00, 0xFC, 0x43, 0x43, 0x4F,
0x3F, 0x0F, 0x03, 0x00, 0x01, 0x02, 0x07, 0x0F, 0x0F, 0x1F, 0x18, 0x30, 0x30, 0x20, 0xA0, 0x60,
0x00, 0x0F, 0x3F, 0x7F, 0xFE, 0xF8, 0xF0, 0xC0, 0xC0, 0xC0, 0x30, 0x08, 0x08, 0x04, 0x02, 0x01,
0x00, 0x00, 0x00, 0x00, 0x00, 0x00, 0x00, 0x00, 0x00, 0x00, 0x00, 0x00, 0x00, 0x00, 0x00, 0x00,
0x00, 0x00, 0x00, 0x00, 0x00, 0x00, 0x00, 0x00, 0x00, 0x00, 0x00, 0x00, 0x00, 0x00, 0x00, 0x00,
0x00, 0x00, 0x00, 0x00, 0x00, 0x00, 0x00, 0x00, 0x00, 0x00, 0x00, 0x00, 0x00, 0x00, 0x00, 0x00,
0x00, 0x00, 0x00, 0x00, 0x00, 0x00, 0x00, 0x00, 0x00, 0x00, 0x00, 0x00, 0x00, 0x00, 0x08, 0x0C,
0x0A, 0x09, 0x08, 0x04, 0x04, 0x02, 0x01, 0x31, 0x3F, 0x11, 0x09, 0x05, 0x03, 0x00, 0x00, 0x00,
0x00, 0x00, 0x00, 0x00, 0x00, 0x00, 0x00, 0x00, 0x00, 0x00, 0x00, 0x00, 0x00, 0x00, 0x00, 0x00,
0x00, 0x00, 0x00, 0x00, 0x00, 0x00, 0x00, 0x00, 0x00, 0x00, 0x00, 0x00, 0x00, 0x00, 0x00, 0x00,
0x00, 0x00, 0x00, 0x00, 0x00, 0x00, 0x00, 0x00, 0x00, 0x00, 0x00, 0x00, 0x00, 0x00, 0x00, 0x00,
0x00, 0x00, 0x00, 0x00, 
};

const unsigned char fish2 [] = {
0x00, 0x00, 0x00, 0x00, 0x00, 0x00, 0x00, 0x00, 0x00, 0x00, 0x00, 0x00, 0x00, 0x00, 0x00, 0x00,
0x00, 0x00, 0x00, 0x00, 0x00, 0x00, 0x00, 0x00, 0x00, 0x00, 0x00, 0x00, 0x00, 0x00, 0x00, 0x00,
0x00, 0x00, 0x00, 0x00, 0x00, 0x00, 0x00, 0x00, 0x00, 0x00, 0x00, 0x00, 0x00, 0x00, 0x00, 0x00,
0x00, 0x00, 0x00, 0x00, 0x00, 0x00, 0xE0, 0xA0, 0xE0, 0x00, 0x0E, 0x0A, 0x0E, 0x00, 0x00, 0x00,
0x00, 0x00, 0x00, 0x00, 0x00, 0x00, 0x00, 0x00, 0x00, 0x00, 0x00, 0x00, 0x00, 0x00, 0x00, 0x00,
0x00, 0x00, 0x00, 0x00, 0x00, 0x00, 0x00, 0x00, 0x00, 0x00, 0x00, 0x00, 0x00, 0x00, 0x00, 0xE0,
0x40, 0x40, 0x80, 0x00, 0x06, 0x1A, 0x22, 0x24, 0x44, 0x84, 0x88, 0xC8, 0xF8, 0xF8, 0xF8, 0x70,
0x10, 0x10, 0x10, 0x10, 0x20, 0x20, 0xE0, 0xC0, 0xC0, 0xC0, 0x00, 0x00, 0x00, 0x00, 0x00, 0x00,
0x00, 0x00, 0x00, 0x00, 0x00, 0x00, 0x00, 0x00, 0x00, 0x00, 0x80, 0x80, 0x80, 0x1C, 0x14, 0x1C,
0x00, 0x00, 0x00, 0x00, 0x00, 0x00, 0x00, 0x00, 0x00, 0x00, 0x00, 0x00, 0x00, 0x00, 0x00, 0x00,
0x00, 0x00, 0x00, 0x00, 0x00, 0x00, 0x00, 0x00, 0x00, 0x00, 0x00, 0x00, 0x00, 0x00, 0x00, 0x00,
0x00, 0x00, 0x00, 0x0F, 0xF8, 0xFE, 0xFF, 0x3E, 0x1E, 0x60, 0x40, 0x40, 0xA0, 0xFD, 0xFF, 0xFF,
0x1F, 0x03, 0x01, 0x00, 0x00, 0x00, 0x00, 0xF0, 0xFE, 0xFF, 0x3F, 0x0F, 0x03, 0x01, 0x82, 0xC4,
0xC8, 0x08, 0x10, 0x20, 0x20, 0x40, 0x80, 0x00, 0x00, 0x00, 0x70, 0x50, 0x70, 0x00, 0x03, 0x02,
0x03, 0x00, 0x00, 0x00, 0x00, 0x00, 0x00, 0x00, 0x00, 0x00, 0x00, 0x00, 0x00, 0x00, 0x00, 0x00,
0x00, 0x00, 0x00, 0x00, 0x00, 0x00, 0x00, 0x00, 0x00, 0x00, 0x00, 0x00, 0x00, 0x00, 0x00, 0x00,
0x00, 0x00, 0x00, 0x00, 0x00, 0x00, 0x00, 0x3E, 0xFF, 0xFF, 0xFF, 0x80, 0x00, 0x80, 0x80, 0x00,
0xFF, 0xFF, 0xFF, 0x83, 0x00, 0x00, 0x00, 0x00, 0x00, 0x00, 0x00, 0xFF, 0xFF, 0xFF, 0x00, 0x00,
0x00, 0x00, 0x00, 0x01, 0x01, 0x00, 0x00, 0x10, 0x38, 0xA8, 0x6C, 0x03, 0x00, 0x00, 0x00, 0x00,
0x00, 0x00, 0x00, 0x00, 0x00, 0x00, 0x00, 0x00, 0x00, 0x00, 0x00, 0x00, 0x00, 0x00, 0x00, 0x00,
0x00, 0x00, 0x00, 0x00, 0x00, 0x00, 0x00, 0x00, 0x00, 0x00, 0x00, 0x00, 0x00, 0x00, 0x00, 0x00,
0x00, 0x00, 0x00, 0x00, 0x00, 0x00, 0x00, 0x00, 0x00, 0x00, 0xFC, 0x43, 0x43, 0x4F, 0x3F, 0x0F,
0x03, 0x00, 0x01, 0x02, 0x07, 0x0F, 0x0F, 0x1F, 0x18, 0x30, 0x30, 0x20, 0xA0, 0x60, 0x00, 0x0F,
0x3F, 0x7F, 0xFE, 0xF8, 0xF0, 0xC0, 0xC0, 0xC0, 0x30, 0x08, 0x08, 0x04, 0x02, 0x01, 0x00, 0x00,
0x00, 0x00, 0x00, 0x00, 0x00, 0x00, 0x00, 0x00, 0x00, 0x00, 0x00, 0x00, 0x00, 0x00, 0x00, 0x00,
0x00, 0x00, 0x00, 0x00, 0x00, 0x00, 0x00, 0x00, 0x00, 0x00, 0x00, 0x00, 0x00, 0x00, 0x00, 0x00,
0x00, 0x00, 0x00, 0x00, 
};

const unsigned char fish3 [] = {
0x00, 0x00, 0x00, 0x00, 0x00, 0x00, 0x00, 0x00, 0x00, 0x00, 0x00, 0x00, 0x00, 0x00, 0x00, 0x00,
0x00, 0x00, 0x00, 0x00, 0x00, 0x00, 0x00, 0x00, 0x00, 0x00, 0x00, 0x00, 0x00, 0x00, 0x00, 0x00,
0x00, 0x00, 0x00, 0xF8, 0x10, 0x90, 0xE0, 0x80, 0x81, 0x06, 0x08, 0x09, 0x11, 0x61, 0xE2, 0xF2,
0xFE, 0xFE, 0x7E, 0x1C, 0x04, 0x04, 0x04, 0x04, 0x88, 0xC8, 0xF8, 0xF0, 0xF0, 0x70, 0x80, 0x00,
0x00, 0x00, 0x00, 0x00, 0x00, 0x00, 0x00, 0x00, 0x00, 0x00, 0x00, 0x00, 0x00, 0x00, 0x00, 0x00,
0x38, 0x28, 0x38, 0x01, 0x00, 0x00, 0x00, 0x00, 0x00, 0x00, 0x00, 0x00, 0x00, 0x00, 0x00, 0x00,
0x00, 0x00, 0x00, 0x00, 0x00, 0x00, 0x00, 0x00, 0x00, 0x00, 0x00, 0x00, 0x00, 0x00, 0x00, 0x00,
0x00, 0x00, 0x00, 0x00, 0x00, 0x00, 0x00, 0x83, 0xFE, 0xFF, 0xFF, 0x0F, 0x07, 0x18, 0x10, 0x10,
0xE8, 0xFF, 0xFF, 0xFF, 0x07, 0x00, 0x00, 0x00, 0x00, 0x00, 0x00, 0xFC, 0xFF, 0xFF, 0x0F, 0x03,
0x00, 0x00, 0x20, 0x71, 0x72, 0x02, 0x04, 0x08, 0x08, 0x10, 0x20, 0xC0, 0x00, 0x00, 0x00, 0x00,
0x07, 0x05, 0x07, 0x00, 0x00, 0x00, 0x00, 0x00, 0x00, 0x00, 0x00, 0x00, 0x00, 0x00, 0x00, 0x00,
0x00, 0x00, 0x00, 0x00, 0x00, 0x00, 0x00, 0x00, 0x00, 0x00, 0x00, 0x00, 0x00, 0x00, 0x00, 0x00,
0x00, 0x00, 0x00, 0x00, 0x00, 0x00, 0x00, 0x00, 0x00, 0x00, 0x00, 0xCF, 0xFF, 0xFF, 0xFF, 0xE0,
0xC0, 0x20, 0x60, 0x80, 0xFF, 0xFF, 0xFF, 0xE0, 0x00, 0x00, 0x00, 0x00, 0x00, 0x00, 0x00, 0xFF,
0xFF, 0xFF, 0x80, 0x00, 0x00, 0x00, 0x00, 0x00, 0x00, 0x00, 0x00, 0x04, 0x8E, 0x6A, 0x1B, 0x00,
0x00, 0x00, 0x00, 0x00, 0x00, 0x00, 0x00, 0x00, 0x00, 0x00, 0x00, 0x00, 0x00, 0x00, 0x00, 0x00,
0x00, 0x00, 0x00, 0x00, 0x00, 0x00, 0x00, 0x00, 0x00, 0x00, 0x00, 0x00, 0x00, 0x00, 0x00, 0x00,
0x00, 0x00, 0x00, 0x00, 0x00, 0x00, 0x00, 0x00, 0x00, 0x00, 0x00, 0x00, 0x00, 0x00, 0x3F, 0x10,
0x10, 0x13, 0x0F, 0x03, 0x00, 0x00, 0x00, 0x00, 0x01, 0x03, 0x03, 0x07, 0x06, 0x0C, 0x8C, 0x48,
0x28, 0x18, 0x00, 0x83, 0x4F, 0x5F, 0xFF, 0x7E, 0x7C, 0x70, 0xF0, 0x30, 0x0C, 0x02, 0x02, 0x01,
0x00, 0x00, 0x00, 0x00, 0x00, 0x00, 0x00, 0x00, 0x00, 0x00, 0x00, 0x00, 0x00, 0x00, 0x00, 0x00,
0x00, 0x00, 0x00, 0x00, 0x00, 0x00, 0x00, 0x00, 0x00, 0x00, 0x00, 0x00, 0x00, 0x00, 0x00, 0x00,
0x00, 0x00, 0x00, 0x00, 0x00, 0x00, 0x00, 0x00, 0x00, 0x00, 0x00, 0x00, 0x00, 0x00, 0x00, 0x00,
0x00, 0x00, 0x00, 0x00, 0x00, 0x00, 0x00, 0x00, 0x00, 0x00, 0x00, 0x00, 0x00, 0x00, 0x00, 0x00,
0x02, 0x03, 0x02, 0x02, 0x02, 0x01, 0x01, 0x00, 0x00, 0x0C, 0x0F, 0x04, 0x02, 0x01, 0x00, 0x00,
0x00, 0x00, 0x00, 0x00, 0x00, 0x00, 0x00, 0x00, 0x00, 0x00, 0x00, 0x00, 0x00, 0x00, 0x00, 0x00,
0x00, 0x00, 0x00, 0x00, 
};
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
int main(void) 
{
	int timer = 0;
	uchar state = 1;
	uchar i;
	uchar frame = 0;
	BUZZER = 1;
	system_init();
	wait100ms();

	
	while(one)
	{         
		LED_GREEN = 0;
		LED_RED = 0;
		BUZZER = 1;
		
		if(XCVR_IRQ == 0)
		  locate_wristband();
		low_battery_detect();
				
		if(state == 0)  //idle state (LCD off)
		{
			if(BUTTON) 
			{
				state = 1;
				lcd_backlight(1); 
				frame = 0;
				timer = 0;
			}
		} 
		else if(state == 1)  //LCD on, fish swims 5x
		{
			if(BUTTON) 
			{
				wait100ms();
				if(BUTTON) //check to see that button has been held down
					state = 2;
		    }
			lcd_display(batt_level, frame);
			timer++;
			frame++;
			if(timer > 40) 
			{
				state = 0;
				lcd_clear();
				lcd_backlight(0); 
			}
			if(frame > 4) 
				frame = 0; 
		} 
		else if(state == 2) //if button held down when screen is on, go into sync mode
		{
		  wristband_sync();
		  state = 1;
		}
		wait5ms();
	}
}

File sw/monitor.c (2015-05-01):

/*************************************************************
*       Siemens Re-chargeable Emergency Notifier Wristband (SIREN)
*       EE459 Spring 2011 Team 5A(monitor): Christopher Cortes, Alexander Nobles, Steven Spinn
*************************************************************/

#include <hidef.h> /* for EnableInterrupts macro */
#include <string.h>
#include "derivative.h" /* include peripheral declarations */

/*
  The following puts the dummy interrupt service routine at
  location MY_ISR_ROM which is defined in the PRM file as
  the start of the FLASH ROM
*/

#pragma CODE_SEG MY_ISR_ROM

#pragma TRAP_PROC
void dummyISR(void)
{
}

/*
  This pragma sets the code storage back to default area of ROM as defined in
  the PRM file.
*/

#pragma CODE_SEG DEFAULT

typedef unsigned char uchar;
typedef unsigned int uint;

#define XCVR_RxANT    PTD_PTD4   
#define XCVR_TxANT    PTD_PTD3    
#define XCVR_IRQ      PTD_PTD2   
#define XCVR_CSN      PTD_PTD0 
#define XCVR_SCK      PTD_PTD1   
#define XCVR_SDI      PTD_PTD6 
#define XCVR_SDO      PTD_PTD7

//Global Variables
uchar locate[17] =     {0x29, 0x12, 0x34, 0x56, 0x34, 0x35, 0x36, 0x37, 0x38, 0x39, 0x3A, 0x3B, 0x3C, 0x3D, 0x3E, 0x3F, 0x78};
uchar doneLocate[17] = {0x28, 0x12, 0x34, 0x56, 0x34, 0x35, 0x36, 0x37, 0x38, 0x39, 0x3A, 0x3B, 0x3C, 0x3D, 0x3E, 0x3F, 0x78};
uchar sendSyncID[17] = {0x26, 0x12, 0x34, 0x56, 0x34, 0x35, 0x36, 0x37, 0x38, 0x39, 0x3A, 0x3B, 0x3C, 0x3D, 0x3E, 0x3F, 0x78};

uchar RF_RXBUF[35];
uchar syncList[6][3];
unsigned char one = 1;
void initialize(void);
void strout(int, unsigned char *);
void iniout(unsigned char);
void cmdout(unsigned char);
void datout(unsigned char);
void nibout(unsigned char);
void busywt(void);
void del1m(int);
void del40u(int);
unsigned char checkKeypadInput(void);
void lcd_write(int, unsigned char*);
void clearLCD(void);
void setPassword(void);
unsigned char enterPwd(void);
void waitForDelay(void);
void waitForEnter(void);
void syncWristbands(void);
void locateWristbands(void);
void armSystem(void);
void disarmSystem(void);
void checkAlarm(void);
void write0(void);
void write1(void);
void writeByte(char address, char data);
char readByte(char address);
void init_RFM22(void);
void to_tx_mode(char[], char);
void to_rx_mode(void);
void rx_reset(void);
void send_read_address(uchar addr);
uchar send_command(void);

volatile struct {
  unsigned char Keypad:4;
} MyPTA @0x0000;

#define Keypad MyPTA.Keypad
#define KEYPAD_VALID !PTA_PTA4
#define LCD1 0
#define LCD2 0x40
#define ALARM_BUZZER PTA_PTA5

/*
  This pragma sets the area for allocating variables to the zero page
  of RAM (0x00 to 0xff) for more efficient access.
*/

#pragma DATA_SEG __SHORT_SEG MY_ZEROPAGE

unsigned char delay0;
unsigned char delay1;
unsigned char delay2;


unsigned char pwd[4];
unsigned char armed;
unsigned char state; //State 0 -> Initial state - set password
                     //State 1 -> Menu - Arm/Disarm
                     //State 2 -> Menu - Change Pwd
					 //State 3 -> Menu - Sync Wristband
					 //State 4 -> Menu - Locate Wristband
					 //State 5 -> Enter Pwd - *Not used*
					 //State 6 -> Change Pwd - *Not used*
					 //State 7 -> Status
					 
					 //Current Keypad Configuration
					 // * -> Left
					 // # -> Right
					 // A -> Menu
					 // B -> CLR
					 // C -> Bksp
					 // D -> Enter
					 
unsigned char alarmActive;
					 
                     
                     

/*
  This pragma sets the area for allocating variables back to the default area
  of RAM as defined in the PRM file.
*/

#pragma DATA_SEG DEFAULT

/*
    Declare these strings as "const" so they are allocated in ROM
*/




const unsigned char statusHdr[] = "PROTECTION STATUS:";
const unsigned char statusEn[] = "<< ENABLED >>";
const unsigned char statusDis[] = "<< DISABLED >>";
const unsigned char menuHdr[] = "Main Menu";
const unsigned char menuDisable[] = "> Disable Alarm";
const unsigned char menuEnable[] = "> Enable Alarm";
const unsigned char menuSetPwd[] = "> Set Password";
const unsigned char menuChangePwd[] = "> Change Password";
const unsigned char menuLocate[] = "> Locate Wristband";
const unsigned char menuSync[] = "> Sync Wristband";

const unsigned char setPwdHdr[] = "Set 4 Digit Password";
const unsigned char reenterPwdHdr[] = "Re-enter to confirm:";
const unsigned char enterPwdHdr[] = "Enter Password";


const unsigned char locateHdr[] =  "Locating Wristbands";
const unsigned char locateStop[] = "> Stop";

const unsigned char syncHdr[] =  "Press Sync button on";
const unsigned char syncInstr[] = "wristband to sync.";

const unsigned char pwdChanged[] = "Password changed";
const unsigned char pwdChanged2[] = "successfully.";
const unsigned char pwdSet[] = "Password set";
const unsigned char pwdMismatch[] = "Password mismatch.";
const unsigned char tryAgain[] = "Try again.";

const unsigned char incorrectPwd[] = "Incorrect password";
const unsigned char pwdPrompt[] = ">";

const unsigned char systemArmed[] =  "System Armed";
const unsigned char systemDisarmed[] =  "System Disarmed";

const unsigned char syncSuccessHdr[] = "Wristband Synced:";
const unsigned char syncFailureHdr[] = "Sync Failure";



void armSystem()
{
	armed = 1;
	lcd_write(LCD1, (unsigned char *)systemArmed);
	waitForDelay();
}

void disarmSystem()
{
	ALARM_BUZZER = 1;
	alarmActive = 0;
	armed = 0;
	lcd_write(LCD1, (unsigned char *)systemDisarmed);
	waitForDelay();
}

void lcd_write(int addr, unsigned char* c) {
  clearLCD();
  strout(addr, c);
}
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
